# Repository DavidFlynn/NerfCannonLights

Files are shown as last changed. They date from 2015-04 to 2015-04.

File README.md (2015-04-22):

# NerfCannonLights
PIC16F1847, 24 Bit Output PCB

NerfCannonLights receives a pulse from the gun controller and flashes the lights down the barrel.
Open Source GPL v2

Based on a PIC16F1847 and using 3 74HC259 addressable latches to drive transistor outputs.

7 to 24VDC input
I2C is optional, but not used in this version.
200mA per output, 2 amp total for the PCB.

David Flynn
dflynn@oxfordvue.com
(w) +1-626-256-6557
(m) +1-626-893-6654
Oxford V.U.E., Inc.
11711 Clark Street #108
Arcadia, CA 91006 USA

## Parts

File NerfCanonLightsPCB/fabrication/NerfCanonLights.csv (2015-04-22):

Id | Designator | Package | Quantity | Designation | Supplier and ref
1 | C1 | C_Radial_D5_L6_P2.5 | 1 | 2.2uF
2 | C2,C3,C4,C5,C6 | C_0805_HandSoldering | 5 | 0.1uF
3 | C7 | Elko_vert_11.5x8mm_RM3.5 | 1 | 10uF
4 | D1,D2,D3,D4,D5,D6,D7,D8,D9,D10,D11,D12,D13,D14,D15,D16,D17,D18,D19,D20,D21,D22,D23,D24,D25 | LED-1206 | 25 | LED
5 | D26 | Diode-SMA_Handsoldering | 1 | DIODE
6 | P1 | bornier2 | 1 | CONN_2
7 | P2 | bornier3 | 1 | CONN_3
8 | P3,P4,P5 | Pin_Header_Straight_2x08 | 3 | CONN_8X2
9 | Q1,Q2,Q3,Q4,Q5,Q6,Q7,Q8,Q9,Q10,Q11,Q12,Q13,Q14,Q15,Q16,Q17,Q18,Q19,Q20,Q21,Q22,Q23,Q24 | TO92DGS | 24 | 2N7000
10 | R1,R3,R5,R7,R9,R11,R13,R15,R17,R19,R21,R23,R25,R27,R29,R31,R33,R35,R37,R39,R41,R43,R45,R47 | R_0805_HandSoldering | 24 | 47Ω
11 | R2,R4,R6,R8,R10,R12,R14,R16,R18,R20,R22,R24,R26,R28,R30,R32,R34,R36,R38,R40,R42,R44,R46,R48,R49 | R_0805_HandSoldering | 25 | 1KΩ
12 | R50,R51,R52 | R_0805_HandSoldering | 3 | 4.7KΩ
13 | R53,R54,R55,R56,R57,R58,R59,R60,R61,R62,R63,R64,R65,R66,R67,R68,R69,R70,R71,R72,R73,R74,R75,R76 | R_0805_HandSoldering | 24 | 470Ω
14 | U1 | DIP-18__300 | 1 | PIC16F1847
15 | U2,U3,U4 | SOIC-16_3.9x9.9mm_Pitch1.27mm | 3 | 74LS259
16 | VR1 | LM78XXV | 1 | 7805
17 | H1,H2 | MountingHole_3-7mm | 2 | MountingHole_3-7mm

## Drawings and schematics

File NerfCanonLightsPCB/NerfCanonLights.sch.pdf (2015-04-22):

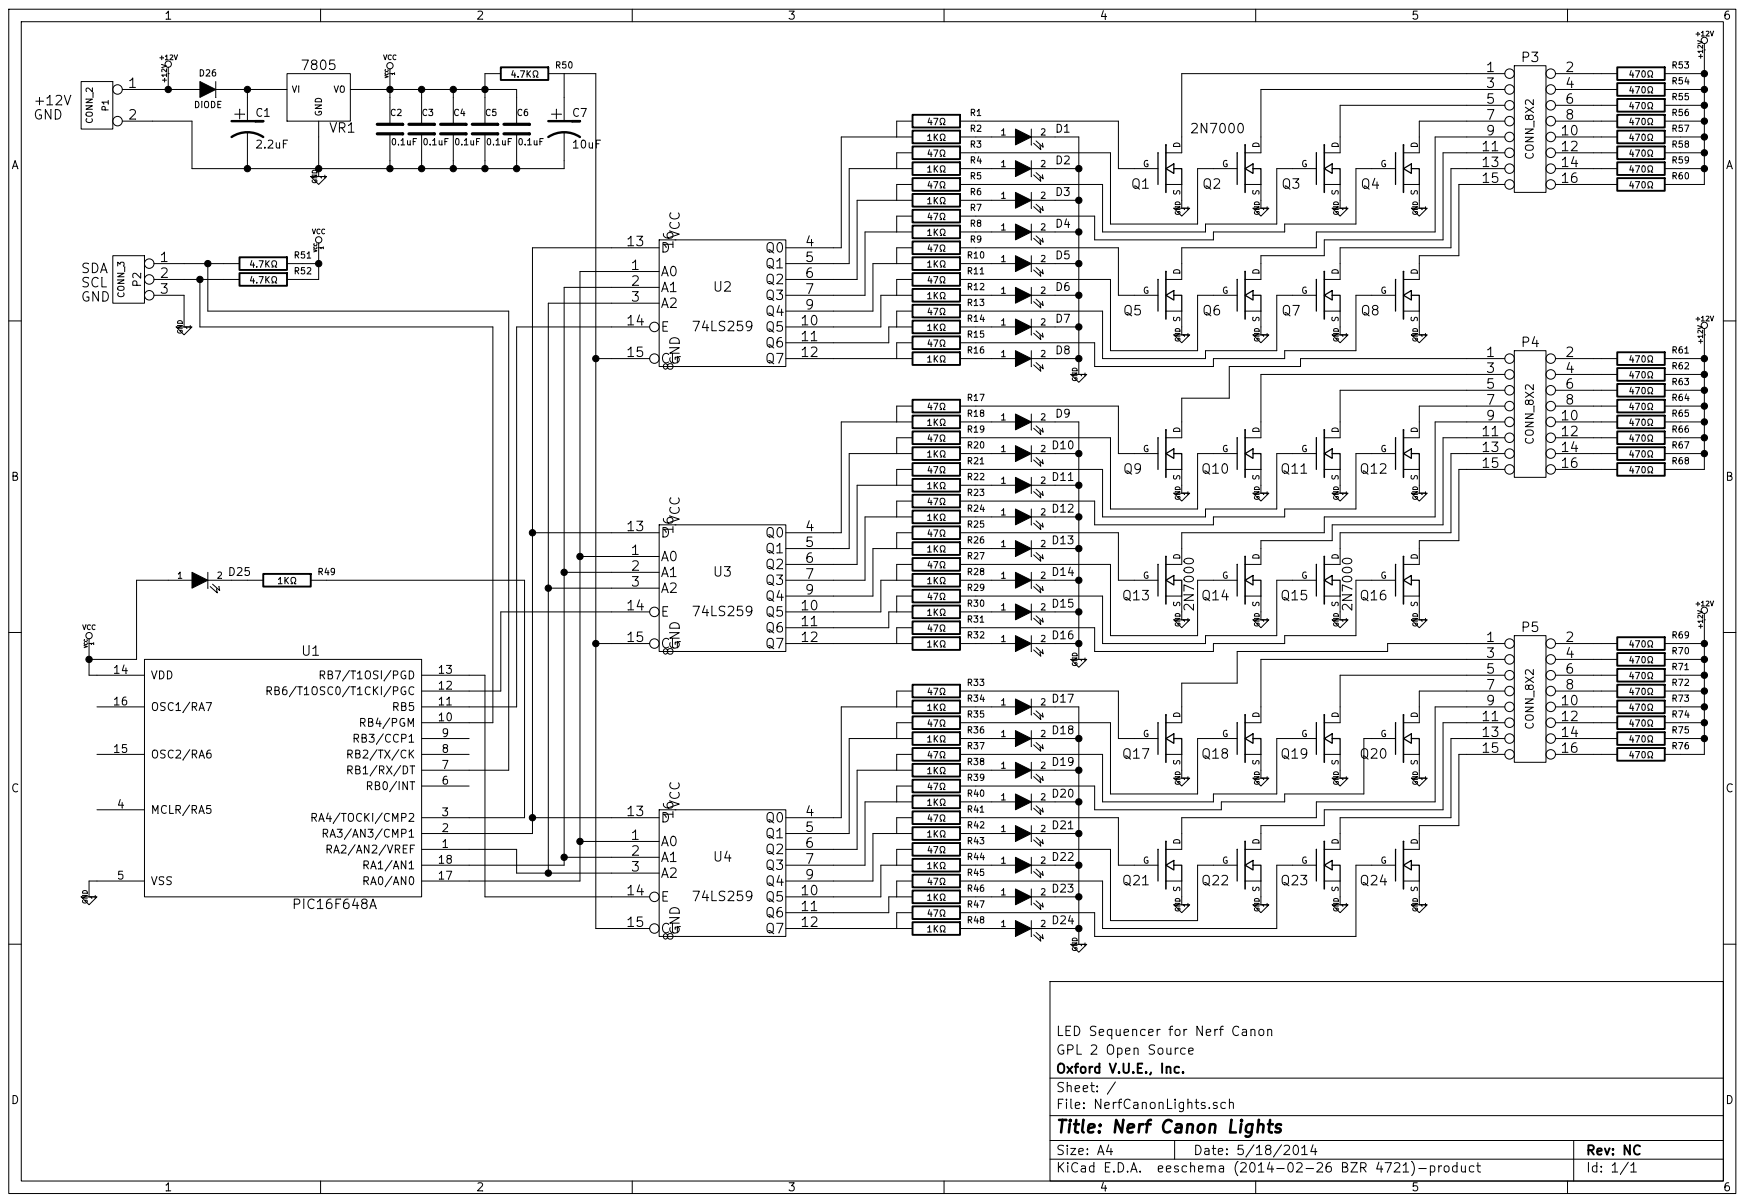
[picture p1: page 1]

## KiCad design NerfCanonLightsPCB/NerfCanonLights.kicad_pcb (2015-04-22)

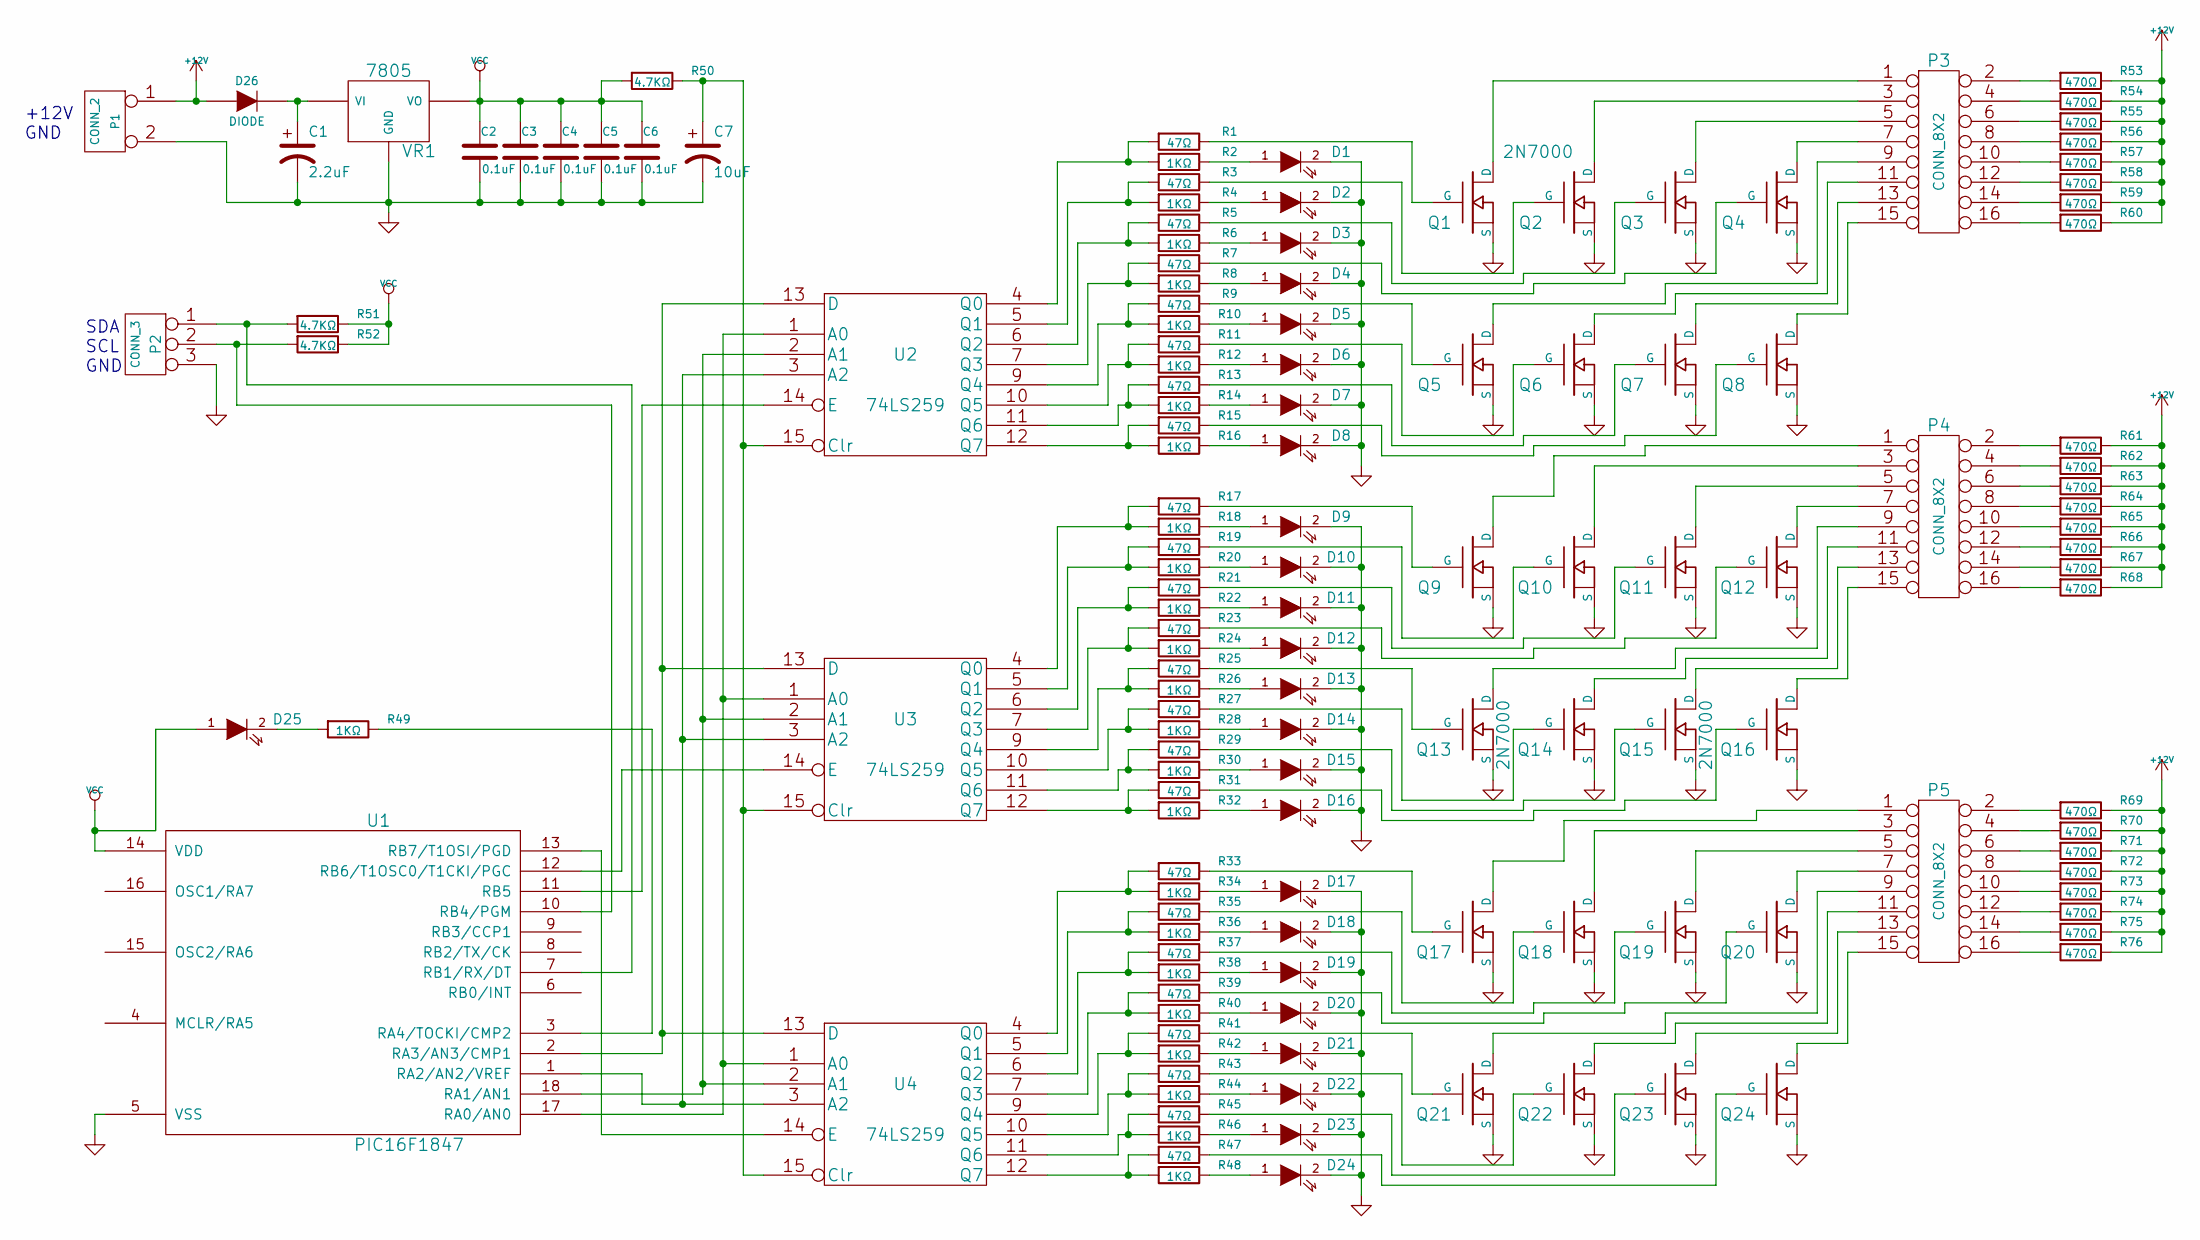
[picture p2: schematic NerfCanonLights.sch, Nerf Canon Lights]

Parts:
C1: 2.2uF; C_Radial_D5_L6_P2.5
C2, C3, C4, C5, C6: 0.1uF; C_0805_HandSoldering
C7: 10uF; Elko_vert_11.5x8mm_RM3.5
D1, D2, D3, D4, D5, D6, D7, D8, D9, D10, D11, D12, D13, D14, D15, D16, D17, D18, D19, D20, D21, D22, D23, D24, D25: LED; LED-1206
D26: DIODE; Diode-SMA_Handsoldering
P1: CONN_2; bornier2
P2: CONN_3; bornier3
P3, P4, P5: CONN_8X2; Pin_Header_Straight_2x08
Q1, Q2, Q3, Q4, Q5, Q6, Q7, Q8, Q9, Q10, Q11, Q12, Q13, Q14, Q15, Q16, Q17, Q18, Q19, Q20, Q21, Q22, Q23, Q24: 2N7000; TO92DGS
R1, R3, R5, R7, R9, R11, R13, R15, R17, R19, R21, R23, R25, R27, R29, R31, R33, R35, R37, R39, R41, R43, R45, R47: 47Ω; R_0805_HandSoldering
R2, R4, R6, R8, R10, R12, R14, R16, R18, R20, R22, R24, R26, R28, R30, R32, R34, R36, R38, R40, R42, R44, R46, R48, R49: 1KΩ; R_0805_HandSoldering
R50, R51, R52: 4.7KΩ; R_0805_HandSoldering
R53, R54, R55, R56, R57, R58, R59, R60, R61, R62, R63, R64, R65, R66, R67, R68, R69, R70, R71, R72, R73, R74, R75, R76: 470Ω; R_0805_HandSoldering
U1: PIC16F1847; DIP-18__300
U2, U3, U4: 74LS259; SOIC-16_3.9x9.9mm_Pitch1.27mm
VR1: 7805; LM78XXV

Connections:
+12V: D26.1 (A), P1.1, R53.1, R54.1, R55.1, R56.1, R57.1, R58.1, R59.1, R60.1, R61.1, R62.1, R63.1, R64.1, R65.1, R66.1, R67.1, R68.1, R69.1, R70.1, R71.1, R72.1, R73.1, R74.1, R75.1, R76.1
GND: C1.2, C2.2, C3.2, C4.2, C5.2, C6.2, C7.2, D1.2 (K), D2.2 (K), D3.2 (K), D4.2 (K), D5.2 (K), D6.2 (K), D7.2 (K), D8.2 (K), D9.2 (K), D10.2 (K), D11.2 (K), D12.2 (K), D13.2 (K), D14.2 (K), D15.2 (K), D16.2 (K), D17.2 (K), D18.2 (K), D19.2 (K), D20.2 (K), D21.2 (K), D22.2 (K), D23.2 (K), D24.2 (K), P1.2 (PM), P2.3, Q1.S, Q2.S, Q3.S, Q4.S, Q5.S, Q6.S, Q7.S, Q8.S, Q9.S, Q10.S, Q11.S, Q12.S, Q13.S, Q14.S, Q15.S, Q16.S, Q17.S, Q18.S, Q19.S, Q20.S, Q21.S, Q22.S, Q23.S, Q24.S, U1.5 (VSS), U2.8 (GND), U3.8 (GND), U4.8 (GND), VR1.GND
unnamed: C1.1, D26.2 (K), VR1.VI
unnamed: C7.1, R50.1, U2.15 (Clr), U3.15 (Clr), U4.15 (Clr)
unnamed: D1.1 (A), R2.1
unnamed: D2.1 (A), R4.1
unnamed: D3.1 (A), R6.1
unnamed: D4.1 (A), R8.1
unnamed: D5.1 (A), R10.1
unnamed: D6.1 (A), R12.1
unnamed: D7.1 (A), R14.1
unnamed: D8.1 (A), R16.1
unnamed: D9.1 (A), R18.1
unnamed: D10.1 (A), R20.1
unnamed: D11.1 (A), R22.1
unnamed: D12.1 (A), R24.1
unnamed: D13.1 (A), R26.1
unnamed: D14.1 (A), R28.1
unnamed: D15.1 (A), R30.1
unnamed: D16.1 (A), R32.1
unnamed: D17.1 (A), R34.1
unnamed: D18.1 (A), R36.1
unnamed: D19.1 (A), R38.1
unnamed: D20.1 (A), R40.1
unnamed: D21.1 (A), R42.1
unnamed: D22.1 (A), R44.1
unnamed: D23.1 (A), R46.1
unnamed: D24.1 (A), R48.1
unnamed: D25.2 (K), R49.2
unnamed: P2.1, R51.2, U1.7 (RB1/RX/DT)
unnamed: P2.2 (PM), R52.2, U1.10 (RB4/PGM)
unnamed: P3.1, Q1.D
unnamed: P3.2, R53.2
unnamed: P3.3, Q2.D
unnamed: P3.4, R54.2
unnamed: P3.5, Q3.D
unnamed: P3.6, R55.2
unnamed: P3.7, Q4.D
unnamed: P3.8, R56.2
unnamed: P3.9, Q5.D
unnamed: P3.10, R57.2
unnamed: P3.11, Q6.D
unnamed: P3.12, R58.2
unnamed: P3.13, Q7.D
unnamed: P3.14, R59.2
unnamed: P3.15, Q8.D
unnamed: P3.16, R60.2
unnamed: P4.1, Q9.D
unnamed: P4.2, R61.2
unnamed: P4.3, Q10.D
unnamed: P4.4, R62.2
unnamed: P4.5, Q11.D
unnamed: P4.6, R63.2
unnamed: P4.7, Q12.D
unnamed: P4.8, R64.2
unnamed: P4.9, Q13.D
unnamed: P4.10, R65.2
unnamed: P4.11, Q14.D
unnamed: P4.12, R66.2
unnamed: P4.13, Q15.D
unnamed: P4.14, R67.2
unnamed: P4.15, Q16.D
unnamed: P4.16, R68.2
unnamed: P5.1, Q17.D
unnamed: P5.2, R69.2
unnamed: P5.3, Q18.D
unnamed: P5.4, R70.2
unnamed: P5.5, Q19.D
unnamed: P5.6, R71.2
unnamed: P5.7, Q20.D
unnamed: P5.8, R72.2
unnamed: P5.9, Q21.D
unnamed: P5.10, R73.2
unnamed: P5.11, Q22.D
unnamed: P5.12, R74.2
unnamed: P5.13, Q23.D
unnamed: P5.14, R75.2
unnamed: P5.15, Q24.D
unnamed: P5.16, R76.2
unnamed: Q1.G, R1.1
unnamed: Q2.G, R3.1
unnamed: Q3.G, R5.1
unnamed: Q4.G, R7.1
unnamed: Q5.G, R9.1
unnamed: Q6.G, R11.1
unnamed: Q7.G, R13.1
unnamed: Q8.G, R15.1
unnamed: Q9.G, R17.1
unnamed: Q10.G, R19.1
unnamed: Q11.G, R21.1
unnamed: Q12.G, R23.1
unnamed: Q13.G, R25.1
unnamed: Q14.G, R27.1
unnamed: Q15.G, R29.1
unnamed: Q16.G, R31.1
unnamed: Q17.G, R33.1
unnamed: Q18.G, R35.1
unnamed: Q19.G, R37.1
unnamed: Q20.G, R39.1
unnamed: Q21.G, R41.1
unnamed: Q22.G, R43.1
unnamed: Q23.G, R45.1
unnamed: Q24.G, R47.1
unnamed: R1.2, R2.2, U2.4 (Q0)
unnamed: R3.2, R4.2, U2.5 (Q1)
unnamed: R5.2, R6.2, U2.6 (Q2)
unnamed: R7.2, R8.2, U2.7 (Q3)
unnamed: R9.2, R10.2, U2.9 (Q4)
unnamed: R11.2, R12.2, U2.10 (Q5)
unnamed: R13.2, R14.2, U2.11 (Q6)
unnamed: R15.2, R16.2, U2.12 (Q7)
unnamed: R17.2, R18.2, U3.4 (Q0)
unnamed: R19.2, R20.2, U3.5 (Q1)
unnamed: R21.2, R22.2, U3.6 (Q2)
unnamed: R23.2, R24.2, U3.7 (Q3)
unnamed: R25.2, R26.2, U3.9 (Q4)
unnamed: R27.2, R28.2, U3.10 (Q5)
unnamed: R29.2, R30.2, U3.11 (Q6)
unnamed: R31.2, R32.2, U3.12 (Q7)
unnamed: R33.2, R34.2, U4.4 (Q0)
unnamed: R35.2, R36.2, U4.5 (Q1)
unnamed: R37.2, R38.2, U4.6 (Q2)
unnamed: R39.2, R40.2, U4.7 (Q3)
unnamed: R41.2, R42.2, U4.9 (Q4)
unnamed: R43.2, R44.2, U4.10 (Q5)
unnamed: R45.2, R46.2, U4.11 (Q6)
unnamed: R47.2, R48.2, U4.12 (Q7)
unnamed: R49.1, U1.3 (RA4/TOCKI/CMP2)
unnamed: U1.1 (RA2/AN2/VREF), U2.3 (A2), U3.3 (A2), U4.3 (A2)
unnamed: U1.2 (RA3/AN3/CMP1), U2.13 (D), U3.13 (D), U4.13 (D)
unnamed: U1.11 (RB5), U2.14 (E)
unnamed: U1.12 (RB6/T1OSC0/T1CKI/PGC), U3.14 (E)
unnamed: U1.13 (RB7/T1OSI/PGD), U4.14 (E)
unnamed: U1.17 (RA0/AN0), U2.1 (A0), U3.1 (A0), U4.1 (A0)
unnamed: U1.18 (RA1/AN1), U2.2 (A1), U3.2 (A1), U4.2 (A1)
VCC: C2.1, C3.1, C4.1, C5.1, C6.1, D25.1 (A), R50.2, R51.1, R52.1, U1.14 (VDD), U2.16 (VCC), U3.16 (VCC), U4.16 (VCC), VR1.VO

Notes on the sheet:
SDA SCL GND
+12V GND

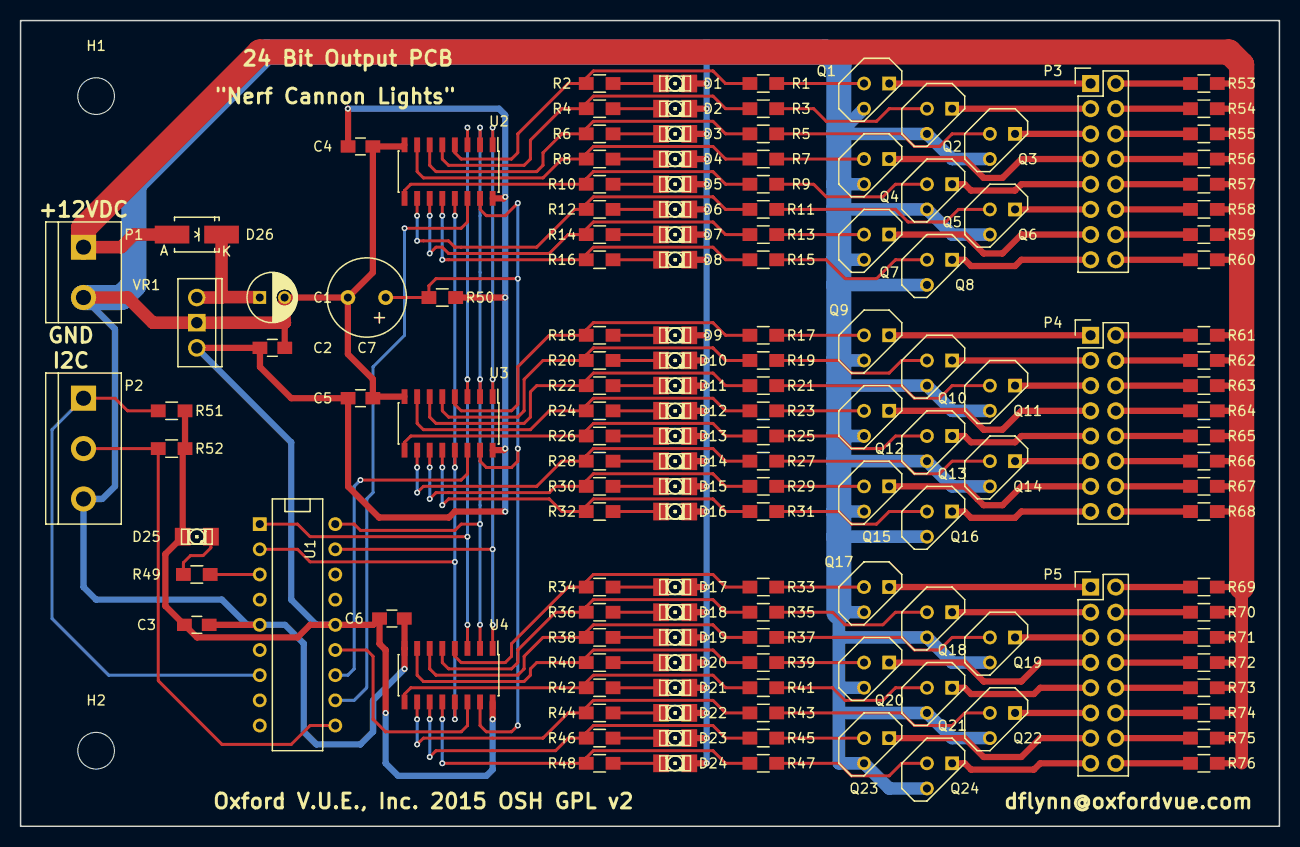
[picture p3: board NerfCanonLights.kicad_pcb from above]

Board: 2 copper layers, 127.0 x 81.3 mm, 145 parts (0 on the bottom side), 136 nets.

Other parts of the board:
H1, H2: MountingHole_3-7mm

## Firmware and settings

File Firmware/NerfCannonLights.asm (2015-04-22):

;====================================================================================================
;
;    Filename:      NerfCannonLights.asm
;    Date:          4/4/2015
;    File Version:  1.0d1
;
;    Author:        David M. Flynn
;    Company:       Oxford V.U.E., Inc.
;    E-Mail:        dflynn@oxfordvue.com
;    Web Site:      http://www.oxfordvue.com/
;
;====================================================================================================
;    NerfCannonLights receives a pulse from the gun controller and 
;      flashes the lights down the barrel.
;
;
;    History:
;
; 1.0d1   4/4/2015	First code. Copied from StepperTest.
;
;====================================================================================================
; Options
;
;====================================================================================================
;====================================================================================================
; What happens next:
;   At power up the system LED will blink and the barrel lights cycle once.
;
;
;====================================================================================================
;
;   Pin 1 (RA2/AN2) Latch address A2 (output)
;   Pin 2 (RA3/AN3) Latch data (active high output)
;   Pin 3 (RA4/AN4) System LED (Active Low Output)
;   Pin 4 (RA5/MCLR*) N.C.
;   Pin 5 (GND) Ground
;   Pin 6 (RB0) N.C.
;   Pin 7 (RB1/AN11/SDA1) I2C Data
;   Pin 8 (RB2/AN10/RX) N.C.
;   Pin 9 (RB3/CCP1) N.C.
;
;   Pin 10 (RB4/AN8/SLC1) I2C Clock
;   Pin 11 (RB5/AN7)  LED0..7 Chip Select (Active Low Output)
;   Pin 12 (RB6/AN5/CCP2) LED8..15 Chip Select (Active Low Output)
;   Pin 13 (RB7/AN6) LED16..23 Chip Select (Active Low Output)
;   Pin 14 (Vcc) +5 volts
;   Pin 15 (RA6) N.C.
;   Pin 16 (RA7) N.C.
;   Pin 17 (RA0) Latch address A0 (output)
;   Pin 18 (RA1) Latch address A1 (output)
;
;====================================================================================================
;
;
	list	p=16f1847,r=hex,W=0	; list directive to define processor
	nolist
	include	p16f1847.inc	; processor specific variable definitions
	list
;
	__CONFIG _CONFIG1,_FOSC_INTOSC & _WDTE_OFF & _MCLRE_OFF & _IESO_OFF
;
;
; INTOSC oscillator: I/O function on CLKIN pin
; WDT disabled
; PWRT disabled
; MCLR/VPP pin function is digital input
; Program memory code protection is disabled
; Data memory code protection is disabled
; Brown-out Reset enabled
; CLKOUT function is disabled. I/O or oscillator function on the CLKOUT pin
; Internal/External Switchover mode is disabled
; Fail-Safe Clock Monitor is enabled
;
	__CONFIG _CONFIG2,_WRT_OFF & _PLLEN_OFF & _LVP_OFF
;
; Write protection off
; 4x PLL disabled
; Stack Overflow or Underflow will cause a Reset
; Brown-out Reset Voltage (Vbor), low trip point selected.
; Low-voltage programming enabled
;
; '__CONFIG' directive is used to embed configuration data within .asm file.
; The lables following the directive are located in the respective .inc file.
; See respective data sheet for additional information on configuration word.
;
	constant	oldCode=0
	constant	useRS232=0
;
#Define	_C	STATUS,C
#Define	_Z	STATUS,Z
;====================================================================================================
	nolist
	include	F1847_Macros.inc
	list
;
;    Port A bits
PortADDRBits	EQU	b'11100000'
#Define	LED_A0	LATA,0	;Output
#Define	LED_A1	LATA,1	;Output
#Define	LED_A2	LATA,2	;Output
#Define	LED_D	LATA,3	;Output
#Define	SystemLED	LATA,4	;Output, 0=LED ON
#Define	RA5_In	PORTA,5	;unused
#Define	RA6_In	PORTA,6	;unused
#Define	RA7_In	PORTA,7	;unused
;
LED_AddrDataMask	EQU	0xF0
;
PortAValue	EQU	b'00010000'
;
;    Port B bits
PortBDDRBits	EQU	b'00011111'	;LEDs Out Others In
;
#Define	RB0_In	PORTB,0	;unused
#Define	RB1_In	PORTB,1	;I2C Data
#Define	RB2_In	PORTB,2	;unused
#Define	RB3_In	PORTB,2	;unused
#Define	RB4_In	PORTB,4	;I2C Clock
#Define	LED0_E	LATB,5	;LED0..7 Chip Select (Active Low Output)
#Define	LED8_E	LATB,6	;LED8..15 Chip Select (Active Low Output)
#Define	LED16_E	LATB,7	;LED16..23 Chip Select (Active Low Output)
;
PortBValue	EQU	b'11100000'
;
;========================================================================================
;========================================================================================
;
;Constants
All_In	EQU	0xFF
All_Out	EQU	0x00
;
TMR0Val	EQU	0xB2	;0xB2=100Hz, 0.000128S/Count
LEDTIME	EQU	d'100'	;1.00 seconds
LEDErrorTime	EQU	d'10'
kWDTime	EQU	d'200'	;2 seconds
;
T1CON_Val	EQU	b'00000001'	;PreScale=1,Fosc/4,Timer ON
TMR1L_Val	EQU	0x3C	; -2500 = 2.5 mS, 400 steps/sec
TMR1H_Val	EQU	0xF6
;
;TMR1L_Val	EQU	0x1E	; -1250 = 1.25 mS, 800 steps/sec
;TMR1H_Val	EQU	0xFB
;
;TMR1L_Val	EQU	0x8F	; -625 = 0.625 mS, 1600 steps/sec
;TMR1H_Val	EQU	0xFD
;
TXSTA_Value	EQU	b'00100000'	;8 bit, TX enabled, Async, low speed
RCSTA_Value	EQU	b'10010000'	;RX enabled, 8 bit, Continious receive
; 8MHz clock low speed (BRGH=0,BRG16=1)
Baud_300	EQU	d'1666'	;0.299, -0.02%
Baud_1200	EQU	d'416'	;1.199, -0.08%
Baud_2400	EQU	d'207'	;2.404, +0.16%
Baud_9600	EQU	d'51'	;9.615, +0.16%
BaudRate	EQU	Baud_9600
;
;
DebounceTime	EQU	d'10'
;
;================================================================================================
;***** VARIABLE DEFINITIONS
; there are 256 bytes of ram, Bank0 0x20..0x7F, Bank1 0xA0..0xEF, Bank2 0x120..0x16F
; there are 256 bytes of EEPROM starting at 0x00 the EEPROM is not mapped into memory but
;  accessed through the EEADR and EEDATA registers
;================================================================================================
;  Bank0 Ram 020h-06Fh 80 Bytes
;
Bank0_Vars	udata	0x20 
;
ISR_Temp	RES	1	;scratch mem
LED_Time	RES	1
lastc	RES	1	;part of tickcount timmer
tickcount	RES	1	;Timer tick count
;
StatLED_Time	RES	1
Stat_Count	RES	1
;
TXByte	RES	1	;Next byte to send
RXByte	RES	1	;Last byte received
WorkingRXByte	RES	1
RS232Flags	RES	1
#Define	DataSentFlag	RS232Flags,0
#Define	DataReceivedFlag	RS232Flags,1
;
;
;
EEAddrTemp	RES	1	;EEProm address to read or write
EEDataTemp	RES	1	;Data to be writen to EEProm
;
;
Timer1Lo	RES	1	;1st 16 bit timer
Timer1Hi	RES	1	; one second RX timeiout
;
Timer2Lo	RES	1	;2nd 16 bit timer
Timer2Hi	RES	1	;
;
Timer3Lo	RES	1	;3rd 16 bit timer
Timer3Hi	RES	1	;GP wait timer
;
Timer4Lo	RES	1	;4th 16 bit timer
Timer4Hi	RES	1	; debounce timer
;
;
SysFlags	RES	1
;
#Define	FirstRAMParam	MinSpdLo
#Define	LastRAMParam	SysFlags
;
;
;================================================================================================
;  Bank2 Ram 120h-16Fh 80 Bytes
;
; I2C Stuff is here
#define	I2C_ADDRESS	0x30	; Slave address
#define	RX_ELEMENTS	.32	; number of allowable array elements, in this case 32
;
Bank2_Vars	udata	0x120   
I2C_ARRAY_TX	res	RX_ELEMENTS	; array to transmit to master
I2C_ARRAY_RX 	res	RX_ELEMENTS 	; array to receive from master
;
;=======================================================================================================
;  Common Ram 70-7F same for all banks
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

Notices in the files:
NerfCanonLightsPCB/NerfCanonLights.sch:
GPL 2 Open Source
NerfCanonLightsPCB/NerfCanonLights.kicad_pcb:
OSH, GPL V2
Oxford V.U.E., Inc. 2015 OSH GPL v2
